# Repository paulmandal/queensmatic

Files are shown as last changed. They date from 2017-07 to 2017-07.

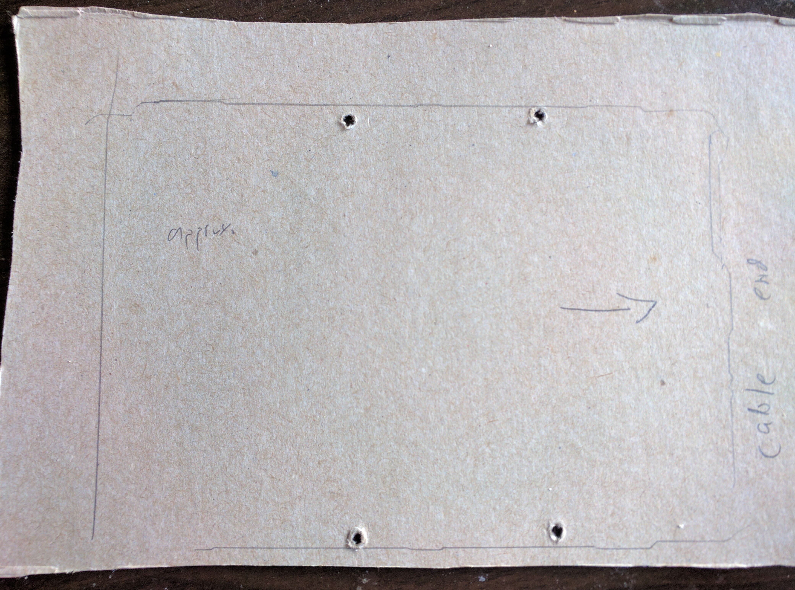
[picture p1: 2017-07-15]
pictures/IMG_20170618_184647.jpg

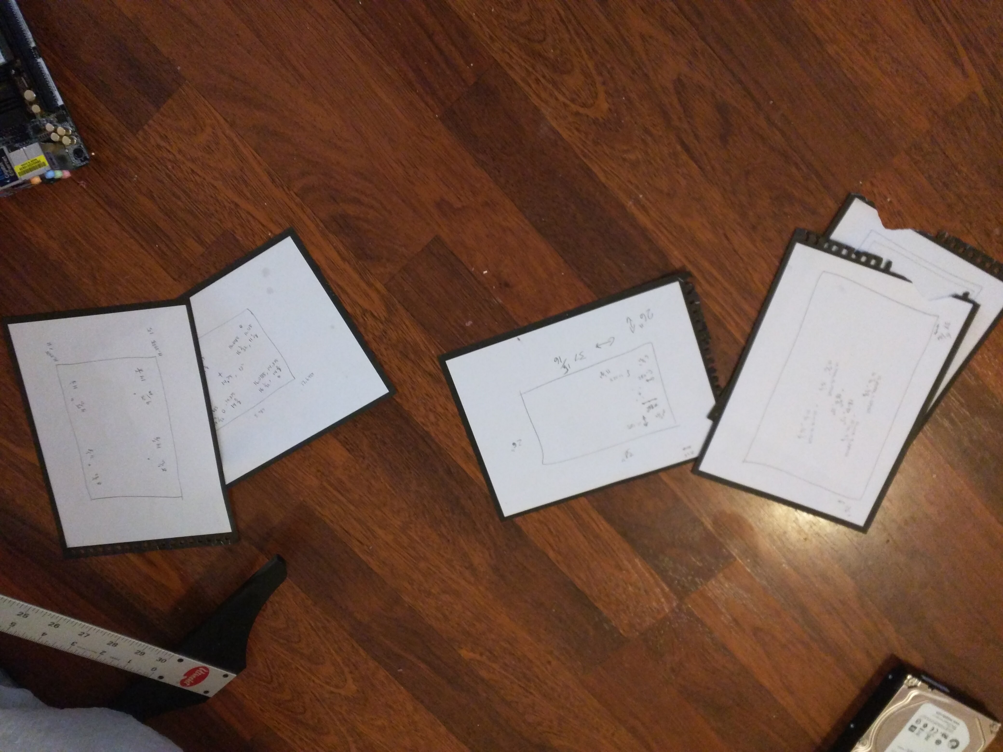
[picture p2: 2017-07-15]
pictures/IMG_20170701_201233.jpg

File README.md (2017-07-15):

# Queensmatic

This project is a wall-mounted NAS with controllable LED strips attached to its case.

# Requirements

- [Python](https://www.python.org/downloads/)
- [Docker CE](https://www.docker.com/community-edition#/download)
- [Android Studio + SDK](https://developer.android.com/studio/index.html)
- [Arduino](https://www.arduino.cc/en/Main/Software)
- [Eagle](https://www.autodesk.com/products/eagle/free-download)

# Table of Contents

| Directory | Contents |
|---|----|
| QueensmaticLEDController | Android LED controller application with simple color picker and touchscreen LED updating |
| hardware/circuit | Eagle schematics for the LED controller PCB |
| led-controller-uservice | Microservice used for communication between the Android app (or apps) and the LED controller hardware |
| ucontroller | Microcontroller code - receives messages from the API via serial and updates the LED strips |
| pictures | Some pictures of the building process |

# Running the API

```
cd led-controller-uservice
virtualenv venv
source venv/bin/activate
pip install docker-compose
# Update docker-compose.yml with the serial port for your microcontroller board -- under "devices"
docker-compose up
```

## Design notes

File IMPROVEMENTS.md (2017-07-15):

## Possible Improvements
- Design assumes a rectangular LED strip arrangement - something more flexible would be cool, but overkill for now
- Define initial DB in .sql file instead of Python file
- Bidirectional communication with the uController for LED state
- Use Python classes for data received by the API
- Move JSON->Native (and vice versa) mapping into API-level (led-controller-api.py)
- Improve touch detection in Android app - determine which strip the user is touching then determine which LED using only that strip's views
- Unit Tests
- Integration Tests
- Circuit with more SMD components instead of through-hole
- Possibly relay to control LED strip power supply
- Color selection pallet in app
- Sleep mode in uController code - use SerialEvent()

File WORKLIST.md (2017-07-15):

# To Do

## Hardware

# In Progress

# Blocked

# Finished
- OS Setup
- Android App - Fix drawing of bottom LED strip (touch detection boxes are right-to-left instead of l-t-r)
- Design Case
  - Airflow
  - Air filtration
  - Computer component placement
  - LED mounting
  - Wall mounting
  - Light-bleed blocking?
- Source screws, dampening grommets, air filters
- Hardware - Build NAS - wait for replacements
- Waiting for components
- Something - Find bottleneck - LEDs aren't updating fast enough, excluded app already, something is wrong in uController or API code (or both)
- Hardware - Select & order hardware
- LED Controller API - Define API in SwaggerHub
- LED Controller API - /configuration endpoint, GET
- LED Controller API - Database / datastore for config
- LED Controller API - /configuration endpoint, PUT
- LED Controller API - /leds endpoint - PUT
- LED Controller API - Init uController with config
- LED uController Software - - Basic skeleton
- LED uController Software - Read config from serial port
- LED uController Software - Read LED update commands from serial port (format: LED#,R,G,B - uint8_t)
- LED uController Software - Update LED Strip
- Android App - App Skeleton - Main Screen
- Android App - Configuration fetching & parsing
- Android App - Configuration Screen (host, top/right/bottom/left LED counts)
- General - First End-to-End Test
- Android App - LED Updating Screen - Skeleton
- Android App - LED Updating Screen - Color & brightness sliders
- Android App - LED Updating Screen - Color Preview & other UI
- Android App - LED Updating Screen - LED display
- Android App - LED Updating Screen - API integration
- Android App - LED Updating Screen - Touch & intersection detection
- Android App - LED Updating Screen - Better abstraction in LED drawing (LayoutParams stuff)
- Hardware - Design circuit in Eagle
- LED Controller API - Add /status endpoint with GET/PUT, wire up to R and P commands in uController, update SwaggerHub
- Hardware - prototype circuit on breadboards - need a SMD soldering iron tip for breakout
- Hardware - Lay out PCB in Eagle
- Android App - Hook up power button/switch
- Some refactors
- Hardware - Order circuit board & SMD parts
- Hardware - Lots of soldering, testing
- LED Controller API - Docker container

# Icebox

- LED Controller API - /leds endpoint - GET
- Update SwaggerHub definition with response object

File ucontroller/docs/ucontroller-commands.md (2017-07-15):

# uController Command Definitions

## Configuration Update

Format: C:n

| Placeholder | Meaning |
| ---| ---|
| n | New number of LEDs the uController is driving |

## LED Update

Format: U:n,r,g,b,br

| Placeholder | Meaning |
| ---| ---|
| n | LED # to update |
| r | Red channel value |
| g | Green channel value |
| b | Blue channel value  |
| br | Brightness |

## Power Update

Format: P:n

| Placeholder | Meaning |
| ---| ---|
| n | 0 for off, 1 for on |

## Status Request

Format: R
Response Format: P:n,T:c

| Placeholder | Meaning |
| ---| ---|
| n | power state, 0 for off, 1 for on |
| c | temperature in C |

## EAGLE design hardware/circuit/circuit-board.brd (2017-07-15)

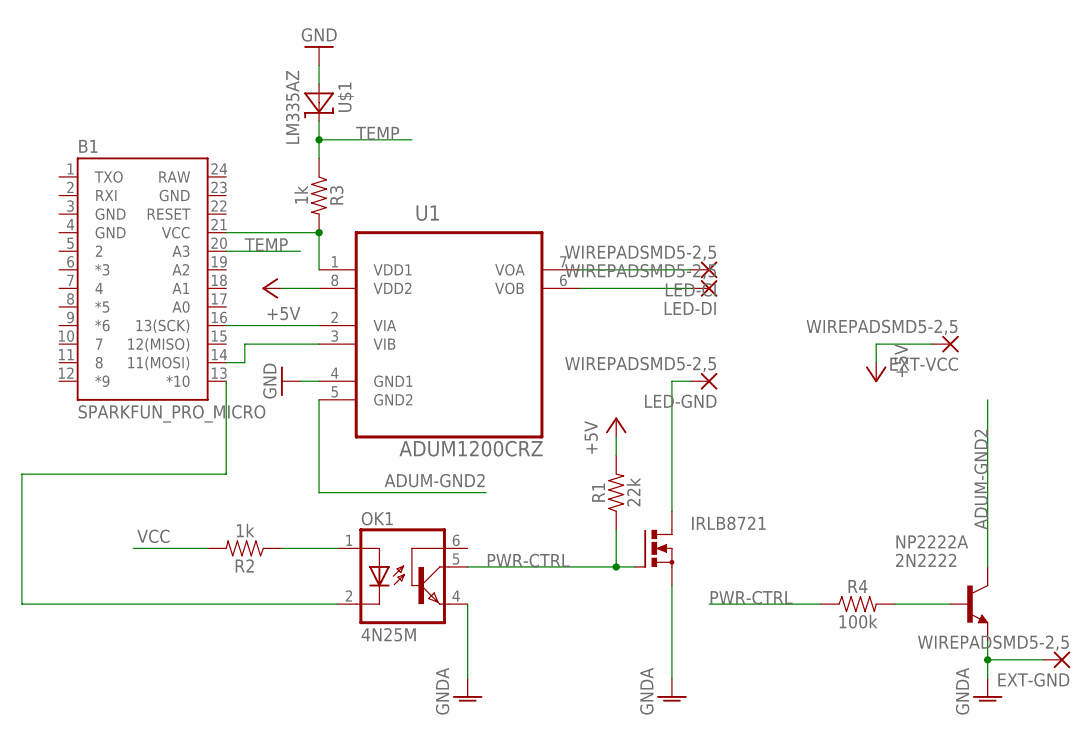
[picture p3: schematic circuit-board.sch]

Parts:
B1: SPARKFUN_PRO_MICRO
EXT-GND: WIREPADSMD5-2,5; 5-2,5
EXT-VCC: WIREPADSMD5-2,5; 5-2,5
IRLB8721: PMOSFET_NTO220BH; TO220BH
LED-CI: WIREPADSMD5-2,5; 5-2,5
LED-DI: WIREPADSMD5-2,5; 5-2,5
LED-GND: WIREPADSMD5-2,5; 5-2,5
NP2222A: 2N2222; TO92-EBC-OVAL
OK1: 4N25M; DIL06
R1: 22k; 0603
R2, R3: 1k; 0603
R4: 100k; 0603
U1: ADUM1200CRZ; SOIC127P600X175-8N
U$1: LM335AZ; TO92-

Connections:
+5V: EXT-VCC.1, R1.2, U1.8 (VDD2)
ADUM-GND2: NP2222A.C, U1.5 (GND2)
GND: B1.3 (GND), B1.4 (GND), B1.23 (GND), U1.4 (GND1), U$1.1 (A)
GNDA: EXT-GND.1, IRLB8721.S, NP2222A.E, OK1.4 (EMI)
unnamed: LED-DI.1, U1.6 (VOB)
unnamed: NP2222A.B, R4.2
unnamed: IRLB8721.D, LED-GND.1
unnamed: OK1.1 (A), R2.1
unnamed: B1.14 (11(MOSI)), U1.3 (VIB)
unnamed: B1.16 (13(SCK)), U1.2 (VIA)
unnamed: LED-CI.1, U1.7 (VOA)
unnamed: B1.13 (*10), OK1.2 (C)
PWR-CTRL: IRLB8721.G, OK1.5 (COL), R1.1, R4.1
RAW: B1.24 (RAW)
TEMP: B1.20 (A3), R3.1, U$1.2 (C)
VCC: B1.21 (VCC), R2.2, R3.2, U1.1 (VDD1)

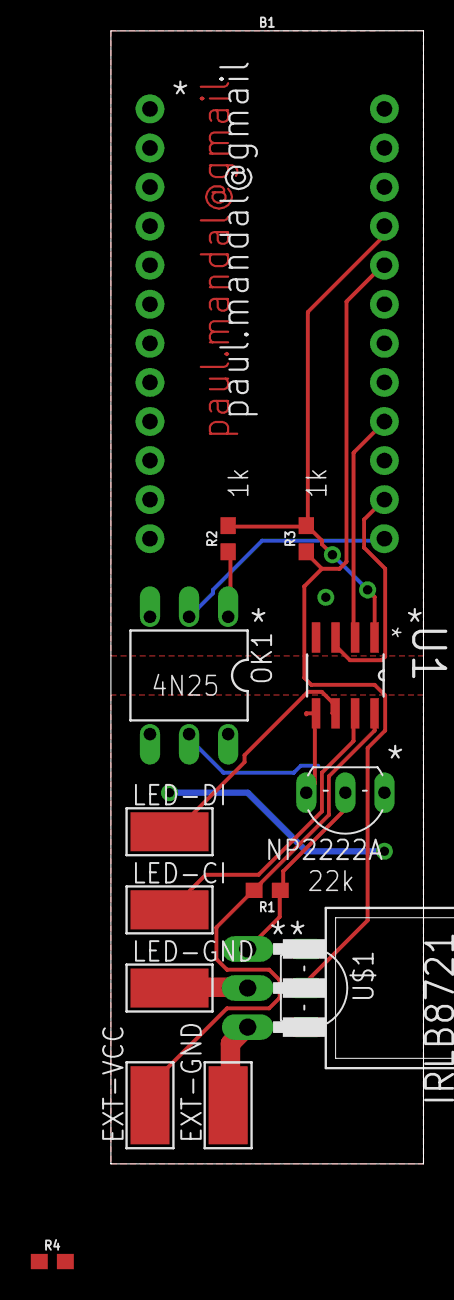
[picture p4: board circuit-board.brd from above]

Board: 2 copper layers, 20.3 x 73.7 mm, 15 parts (0 on the bottom side), 15 nets.

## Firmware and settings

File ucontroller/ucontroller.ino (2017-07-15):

/**
 * LED Controller:
 *  - Receives configuration updates over serial
 *  - Receives LED state updates over serial
 *  - Updates attached LED strip
 */

#include <SPI.h>
#include "led_controller.h"
#include "message_handler.h"

// LED Controller
LedController ledController;

// Hardware Controller - Power & Temperature
HardwareController hardwareController;

// Message Handler
MessageHandler messageHandler;

/**
 * Init code
 */
void setup() {
  ledController.begin(DEFAULT_LED_COUNT);
  hardwareController.begin();
  messageHandler.begin(&ledController, &hardwareController);
}

/**
 * Main loop
 */
void loop() {  
  messageHandler.checkMessages();
  hardwareController.updateTemp();
  hardwareController.checkTemp();
}

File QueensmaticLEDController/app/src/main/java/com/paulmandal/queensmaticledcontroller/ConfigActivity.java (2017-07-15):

package com.paulmandal.queensmaticledcontroller;

import android.content.DialogInterface;
import android.content.Intent;
import android.os.Bundle;
import android.support.annotation.NonNull;
import android.support.v7.app.AlertDialog;
import android.support.v7.app.AppCompatActivity;
import android.view.View;
import android.widget.Button;
import android.widget.TextView;

import com.paulmandal.queensmaticledcontroller.api.LedApi;
import com.paulmandal.queensmaticledcontroller.data.AppConfiguration;
import com.paulmandal.queensmaticledcontroller.data.Configuration;

/**
 * Config activity - update API and app configuration
 */
public class ConfigActivity extends AppCompatActivity {

    /**
     * What to clear the hostname field to
     */
    private static final String EMPTY_HOSTNAME = "http://";

    /**
     * API Connection
     */
    LedApi mLedApi;

    /**
     * Current application configuration
     */
    AppConfiguration mAppConfiguration;

    /**
     * Current LED strip configuration
     */
    Configuration mConfiguration = null;

    /**
     * References to UI elements
     */
    TextView mHostname;
    TextView mTopLedCount;
    TextView mRightLedCount;
    TextView mBottomLedCount;
    TextView mLeftLedCount;
    TextView mStartupBrightness;
    TextView mStartupRed;
    TextView mStartupGreen;
    TextView mStartupBlue;
    Button mSaveButton;

    /**
     * Error alert dialog
     */
    private AlertDialog mAlertDialog;

    @Override
    protected void onCreate(Bundle savedInstanceState) {
        super.onCreate(savedInstanceState);
        setContentView(R.layout.activity_config);

        // Get UI element references
        mHostname = (TextView) findViewById(R.id.hostname);
        mTopLedCount = (TextView) findViewById(R.id.top_led_count);
        mRightLedCount = (TextView) findViewById(R.id.right_led_count);
        mBottomLedCount = (TextView) findViewById(R.id.bottom_led_count);
        mLeftLedCount = (TextView) findViewById(R.id.left_led_count);
        mStartupBrightness = (TextView) findViewById(R.id.startup_brightness);
        mStartupRed = (TextView) findViewById(R.id.startup_red);
        mStartupGreen = (TextView) findViewById(R.id.startup_green);
        mStartupBlue = (TextView) findViewById(R.id.startup_blue);
        mSaveButton = (Button) findViewById(R.id.button_save);

        mHostname.setOnFocusChangeListener(mHostnameFocusListener);
        mSaveButton.setOnClickListener(mSaveButtonListener);

        mAppConfiguration = new AppConfiguration(this);
        mLedApi = LedApi.ledApiFactory(this, mAppConfiguration.getHostname());
    }

    @Override
    public void onResume() {
        super.onResume();
        // Fetch config if hostname is available
        String hostname = mAppConfiguration.getHostname();
        if (hostname != null) {
            mHostname.setText(hostname);
            mAppConfiguration.setHostname(hostname);
            mLedApi.fetchConfiguration(mFetchConfigurationListener);
        } else {
            mHostname.setText(EMPTY_HOSTNAME);
            mHostname.requestFocus();
        }
    }

    @Override
    public void onPause() {
        if (mAlertDialog != null) {
            mAlertDialog.dismiss();
        }
        super.onPause();
    }

    /**
     * Hostname focus listener - attempts to store hostname when it changes & refresh settings from
     * API
     */
    private View.OnFocusChangeListener mHostnameFocusListener = new View.OnFocusChangeListener() {
        @Override
        public void onFocusChange(View v, boolean hasFocus) {
            if (!hasFocus) {
                String hostname = mHostname.getText().toString();
                boolean hostnameChanged = !hostname.equals(mAppConfiguration.getHostname());
                if (!hostname.equals(EMPTY_HOSTNAME) && hostnameChanged) {
                    mAppConfiguration.setHostname(hostname);
                    mLedApi.setHostname(hostname);
                    mLedApi.fetchConfiguration(mFetchConfigurationListener);
                }
            }
        }
    };

    /**
     * Configuration fetching listener
     */
    private LedApi.FetchConfigurationListener mFetchConfigurationListener = new LedApi.FetchConfigurationListener() {
        @Override
        public void onConfigurationFetched(@NonNull Configuration configuration) {
            mConfiguration = configuration;
            updateEditTexts();
        }

        @Override
        public void onConfigurationFetchError() {
            hostnameError();
        }
    };

    /**
     * Configuration storing listener
     */
    private LedApi.StoreConfigurationListener mStoreConfigurationListener = new LedApi.StoreConfigurationListener() {
        @Override
        public void onConfigurationStored() {
            configSaved();
        }
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

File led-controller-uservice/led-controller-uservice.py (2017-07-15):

#!venv/bin/python

#
# LED Controller API
#

from constants import *
from flask import Flask, request, abort, jsonify
import configdb
import ucontroller

app = Flask(__name__)
configdb.maybe_init_database()
ucontroller.set_config(configdb.get_config(), startup=True)


@app.route('/configuration', methods=['GET'])
def get_configuration():
    data = configdb.get_config()
    return jsonify(data)


@app.route('/configuration', methods=['PUT'])
def store_configuration():
    if not request.json:
        abort(400)
    if not any(x in request.json for x in configdb.get_config_columns()):
        abort(400)
    configdb.store_config(request.json)
    ucontroller.set_config(request.json)
    return jsonify(message='configuration updated'), 201


@app.route('/leds', methods=['PUT'])
def update_led():
    if not request.json:
        abort(400)
    if not any(x in request.json for x in LED_UPDATE_FIELDS):
        abort(400)
    json = request.json
    ucontroller.update_led(json['ledNumber'], json['red'], json['green'], json['blue'], json['brightness'])
    return jsonify(message='LED updated'), 201


@app.route('/status', methods=['GET'])
def get_status():
    status = ucontroller.get_status()
    return jsonify(status)


@app.route('/status', methods=['PUT'])
def update_status():
    if not request.json:
        abort(400)
    if 'powerState' not in request.json:
        abort(400)
    ucontroller.update_power(request.json['powerState'])
    return jsonify(message='status updated'), 201


if __name__ == '__main__':
    app.run(debug=True, host='0.0.0.0', port=31337)

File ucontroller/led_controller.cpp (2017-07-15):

/*
 * LED Strip Controller Code
 */
#include "Arduino.h"
#include "led_controller.h"
#include <SPI.h>

// Constants
const long DEVICE_CLOCK_SPEED = 16000000L;
const int DEFAULT_LED_COUNT = 193;
const int LED_UPDATE_VALUE_COUNT = 5;

// Constructor, empty
LedController::LedController() {}

void LedController::begin(int ledCount) {
  currentLedCount = ledCount;  
  _reallocateMemory();
  SPI.begin();
}

/**
 * Call when power state changes
 */
void LedController::powerOn() {
  delay(50);
  _updateLeds();
}

/**
 * Reallocate memory for LED state
 */
void LedController::_reallocateMemory() {
  free(leds);
  leds = (LED*)calloc(currentLedCount, sizeof(LED));  
}

/** 
 * Update the LED count
 */
void LedController::updateLedCount(int ledCount) {
  boolean reallocate = currentLedCount != ledCount;
  if(reallocate) {
    currentLedCount = ledCount;
    _reallocateMemory();
    _updateLeds();
  }
}

/**
 * Update an LED's state
 */
void LedController::updateLed(int ledNumber, int red, int green, int blue, int brightness) {  
  if(ledNumber >= currentLedCount) {
    // LED out of bounds
    return false;
  }
  // Normalize brightness value
  brightness = min(brightness, 31);
  LED *led = &leds[ledNumber];
  boolean needsUpdate = led->red != red
                          || led->green != green
                          || led->blue != blue
                          || led->brightness != brightness;
  if(needsUpdate) {
    led->red = red;
    led->green = green;
    led->blue = blue;
    led->brightness = brightness;
    _updateLeds();
  }
}

/**
 * Send commands to LED hardware to update lights
 */
void LedController::_updateLeds() {  
  // For APA102C
  int endLength = round(((float)(currentLedCount - 1) / 16.0) + 0.5F);
  endLength = max(endLength, 4);
  int i;
  byte headerByte;
  LED *led;
  SPI.beginTransaction(SPISettings(DEVICE_CLOCK_SPEED, MSBFIRST, SPI_MODE0));
  // Start by sending 32 zero bits
  for(i = 0 ; i < 4 ; i++) {
    SPI.transfer(0x00);
  }
  // Send each LED state, header is 1110 0000 & 5-bit brightness, then b/g/r color channels
  for(i = 0 ; i < currentLedCount ; i++) {
    led = &leds[i];
    headerByte = B11100000 | led->brightness;
    SPI.transfer(headerByte);
    SPI.transfer(led->blue);
    SPI.transfer(led->green);
    SPI.transfer(led->red);
  }
  for(i = 0 ; i < endLength ; i++) {
    SPI.transfer(0xFF);
  }
  SPI.endTransaction();  
}

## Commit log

2017-03-11 Added WORKLIST.md to track tasks
2017-03-12 Added /configuration and /leds endpoints, added ucontroller.py to send update LED commands to the uController, added constants.py, Added /configuration and /leds endpoints for updating the config and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
2017-03-12 Fixed an issues with ucontroller.set_config()
    [ucontroller.py]
2017-03-12 Added code to handle updating LEDs from serial commands, added code to output LED status to serial, added some comments,
2017-03-13 Renamed led_controller.ino to ucontroller.ino
2017-03-13 Added code to update LED strip to uController - need to debug LED protocol
2017-03-14 Changed r/g/b/brightness types to byte, normalized brightness value, fixed issue with headerByte not being reset before each LED loop, fixed issue with headerByte using & instead of |, added some deb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
    [ucontroller.ino]
2017-03-14 Removed debugging code, set up controller to update LED strip whenever configuration is changed
2017-03-14 Removed app->hardware r/g/b/brightness level remapping because most phones and LED strips only support 8-bit color
2017-03-15 Added storing of configuration from app->API, added permissions requesting, fixed JSON responses from API
    [ConfigActivity.java, configdb.py]
2017-03-15 Added test button & LED updating to ApiConnection
2017-03-15 Fixed serial communication in Python code
    [ucontroller.py]
2017-03-16 Started implementing LED drawing screen, added config fetching from API
2017-03-16 Finished setting up UI, setting up LED data structs now
2017-03-16 Basic drawing is in place - need to improve touch handling, right now you have to tap each LED but dragging the color over them would be a lot cooler
2017-03-18 Added touch detection to drawing screen, it's in good enough shape for now, time to switch to hardware for a bit..
2017-03-18 Improved error handling in draw screen - user now has the option to re-try fetching the config, or they can cancel and go back to setup
    [DrawingActivity.java]
2017-03-21 Added initial circuit diagram with just components
    [circuit-board.sch]
2017-03-21 Added wiring and some resistor values, replaced ISO7221MDR with ADUM1285CRZ because it has the pin arrangement (both inputs on the same side)
    [circuit-board.sch]
2017-03-21 Added temperature sensor to circuit schematic
    [circuit-board.sch]
2017-03-21 Added power pin toggling control to uController code
2017-03-22 Rerouted wiring for 4N25 optocoupler - signal was being inverted
    [circuit-board.sch]
2017-03-23 Added temperature sensor reading to uController code, added automatic poweroff above 40C
2017-03-23 Added PUT to /status endpoint, wired up to P command in uController
2017-03-23 Fixed incorrect pin assignment in LM335AZ in circuit schematic
    [circuit-board.sch]
2017-03-26 Fixed unit in uController code
    [ucontroller.ino]
2017-03-26 Added code to re-update LED strip after power is switched back on - strip loses its state when power is cut
2017-03-26 Added PN2222A to circuit - disconnects GND2 from ADUM1285CRZ so that current won't leak through the signal lines from the LED strip (LED strip wouldn't power off)
    [circuit-board.sch]
2017-03-26 Finished prototyping board
2017-03-26 Added pictures of testing SPI communication circuit
2017-03-26 Added picture from testing power switch signal output
2017-03-26 Added picture of testing optoisolator and N-channel MOSFET
2017-03-26 Added picture from testing LM335A temperature sensor
2017-03-26 Added picture from testing PN2222A N-channel transistor (power control for ADUM1285CRZ)
2017-03-26 Added picture from testing external power supply - circuit testing done!
2017-03-26 Added solder pads to circuit schematic
    [circuit-board.sch]
2017-03-27 Replaced power/signal holes with SMD pads, added initial PCB layout, changed pins for final board
    [circuit-board.brd, circuit-board.sch]
2017-03-27 Added autorouted routes, thickened GND-A (LED ground thru MOSFET) traces, this will probably do, will run through DRUs and send it out tomorrow
    [circuit-board.brd]
2017-03-27 Added to PCB layout - added ground layers, some labels
    [circuit-board.brd]
2017-03-31 Finished circuit board layout, generating Gerber files now
    [circuit-board.brd]
2017-03-31 Generated Gerber files, sent off to PCB shop, now waiting begins..
    [circuit-board.brd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]
2017-04-01 Added Power and MOSFET Temperature Status update to DrawingActivity, fixed some layout, added celsius string to strings.xml, added SystemStatusWorker to fetch system status updates
    [ApiTranslator.java, DrawingActivity.java]
2017-04-01 Added error stack traces to ApiConnection
2017-04-01 Updated USB serial device name for new hardware, fixed datatype in for mosfet_temperature
    [ucontroller.py]
2017-04-01 Added code to send power switch updates to the LED API
2017-04-01 Renamed some variables in LED API
2017-04-01 Moved Power & temperature control into HardwareController
2017-04-02 More refactoring, fixed issues where LEDs wouldn't update
    [hardware_controller.cpp, led_controller.cpp, message_handler.cpp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]
2017-04-02 Added code to the Android app to reduce the number of LED updates sent to the API
2017-04-02 Fixed parsing of configuration empty strings
    [ConfigActivity.java]
2017-04-02 Fixed powerState reading in LED API
    [message_handler.cpp, ucontroller.py]
2017-04-02 Updated worklist, more hardware times.. Ran into a weird issue - MOSFET might not be turning fully on? will need to read up and debug, hopefully this can be made to work with my existing circuit desi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
2017-04-09 Added missing 100k resistor to base of PN2222A, deleted flawed Gerber files - board layout is not updated for now because I have V2 in mind and PCBs in hand already
    [circuit-board.brd, circuit-board.sch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]
2017-04-12 Fixed an issue with touch detection - view coordinates for boundary rectangles were relative to their layout instead of the screen
    [DrawingActivity.java]
2017-04-15 Finished PCB from OSHPark
2017-04-15 First round of soldering on the PCB
2017-04-15 PCB fully populated
2017-04-15 Small 'patch' for a missing resistor - luckily this mistake didn't mean a new board order
2017-04-16 Removed fullscreen from DrawingActivity - dragging on the screen would open the status bar too much
    [DrawingActivity.java]
2017-04-16 Switched interpreter to Python 3.5, fixed an issue with regex pattern w/ pyserial in 3.5
    [configdb.py, led-controller-uservice.py, ucontroller.py]
2017-04-16 Updated WORKLIST and added api testing script, something is not updating fast enough, it might be good to pool updates - update the strip regularly (if changed) every 10ms or something instead of let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
2017-05-08 Added twinkle.py to test uController - turns out repeatedly opening and closing the serial connection doesn't cause issues with slow updates, updating API code
    [twinkle.py]
2017-05-08 Reworked API code to open and close serial port for each transmission
    [ucontroller.py]
2017-05-08 Fixed an issue where power state was not being read correctly
    [ucontroller.py]
2017-05-08 Updated default LED count in led_controller.cpp and configdb.py
2017-05-08 Fixed layout direction for bottom LED strip in app - LEDs updating in reverse on the physical strip
2017-07-08 Added picture of frame-fitting
2017-07-08 Added picture of frame construction
2017-07-08 Added picture from verifying the frame fit correctly
2017-07-08 Added picture of test mounts on scrap wood
2017-07-08 Added picture of cutting holes in backboard
2017-07-08 Added picture of gluing down LED strips
2017-07-08 Fixed layout orientation for lefthand LED strip
    [DrawingActivity.java]
2017-07-08 Added default values == actual LED lenghts for our hardware
2017-07-08 Updated LED uController code with default LED size -- still fiddling with hardware (some of the strip is not lighting some of the time)
2017-07-12 Added detail picture of LED strip mount
2017-07-12 Added picture of finished frame
2017-07-12 Added picture of finished frame with LED strips lit up purple

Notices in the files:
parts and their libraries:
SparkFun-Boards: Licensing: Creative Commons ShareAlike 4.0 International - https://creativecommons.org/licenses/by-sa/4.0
